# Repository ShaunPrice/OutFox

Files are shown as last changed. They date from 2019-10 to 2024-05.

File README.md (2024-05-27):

# OutFox
This is a volunteer project to help save the endangered Bell turtle species. I'm assisting the "Turtles Forever" project team in developing a fox (and dogs) detection and scaring system that uses Artificial Intelligence (AI) to identify the preditors and ward them off. The main preditor causing the damage has been foxes that are not native to Australia and are destroying the turtle nests.

This is the working prototype (PCB not validated) for the solution. It uses MobileNet AI model as it already detects many species of foxes, dogs and wolves.

*Any assistance in this project is welcome!!!*

## Articles About the Project
https://www.abc.net.au/news/2018-03-07/turtle-hatchlings-offer-hope-endangered-bells-turtle/9522182
https://northerntablelands.lls.nsw.gov.au/resource-hub/media-releases/2016/work-begins-on-bells-turtle-recovery-project

Fox and other nuisance animal detection and frightening device. Uses cameras and AI to detect and identify only the nuisance animals.
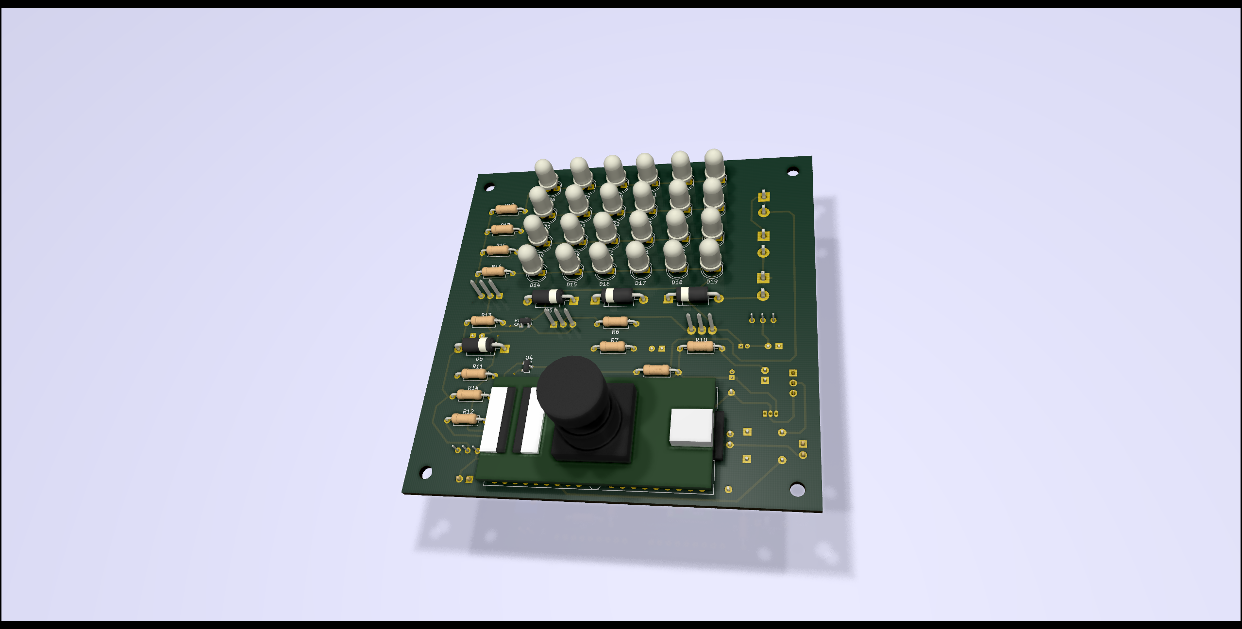
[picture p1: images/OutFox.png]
OutFox Control Board


*This is a Work in Progress*
# Notes for using the Seeed Studio MAIX Bit and the Kendryte K210

## Sipeed MAix BiT for RISC-V AI+IoT
The core of the system is the Sipeed BiT board with camera available from Seeed. 
https://www.seeedstudio.com/Sipeed-MAix-BiT-for-RISC-V-AI-IoT-p-2872.html

This board uses a Kendryte K210 Neural Accellerator for at the edge AI. The board consumes less than 1 Watt of power.

If using this board and camera for night vision using the IR LEDs you'll need to unscrew the lense from the camera and remove the small square IR filter from the back of the lense.

The documentation for this processor is available here:
https://maixpy.sipeed.com/en/

## SiSpeed Downloads
http://dl.sipeed.com/MAIX/
https://github.com/sipeed

## Uploading files and firmware
Use uPyLoader for uploading files and executing script
Use kloader_windows for uploading firmware

The details of obtaining and using these tools is available from the Sipeed website:

https://maixpy.sipeed.com/en/get_started/upload_script.html

## MaixPy Firmware
Builds:   http://dl.sipeed.com/MAIX/MaixPy/release/master/
GitHub: https://github.com/sipeed/MaixPy/releases

## Train, Convert and Run Models for MaixPy 
The following article explains how to train, convert and run AI modules on the MAix BiT and other modules using the Kendryte K210 processor.
https://bbs.sipeed.com/t/topic/682

### Package Kfpkg files
http://blog.sipeed.com/p/390.html
**Note 1:** *SD library does not support long file names.*
**Note 2:** *name.kmodel files are in the zipped file name.kfpkg*

kfpkg files are zipped files containing the following files:

	model.kmodel file that is the inference model
	flash-list.json file that tells the loaded where to put the model in flash memory
	
A typical kfpkg flash-list.json file is below where facedetect.kmodel is the name of the kmodel file:
'''json
{
    "version": "0.1.0",
     "files": [
        {
            "address": 0x00300000,
            "bin": "facedetect.kmodel",
            "sha256Prefix": false
        }
    ]
}
'''

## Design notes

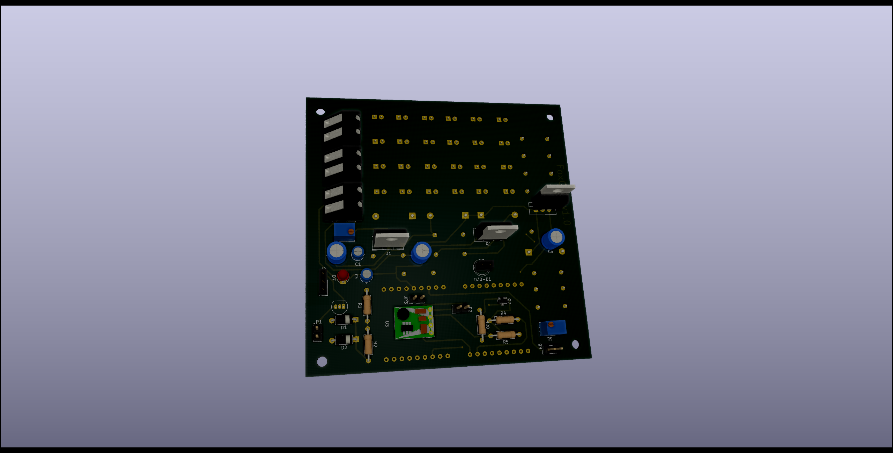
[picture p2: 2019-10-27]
OutFox_KiCAD_Electronics/FoxCam_back.png

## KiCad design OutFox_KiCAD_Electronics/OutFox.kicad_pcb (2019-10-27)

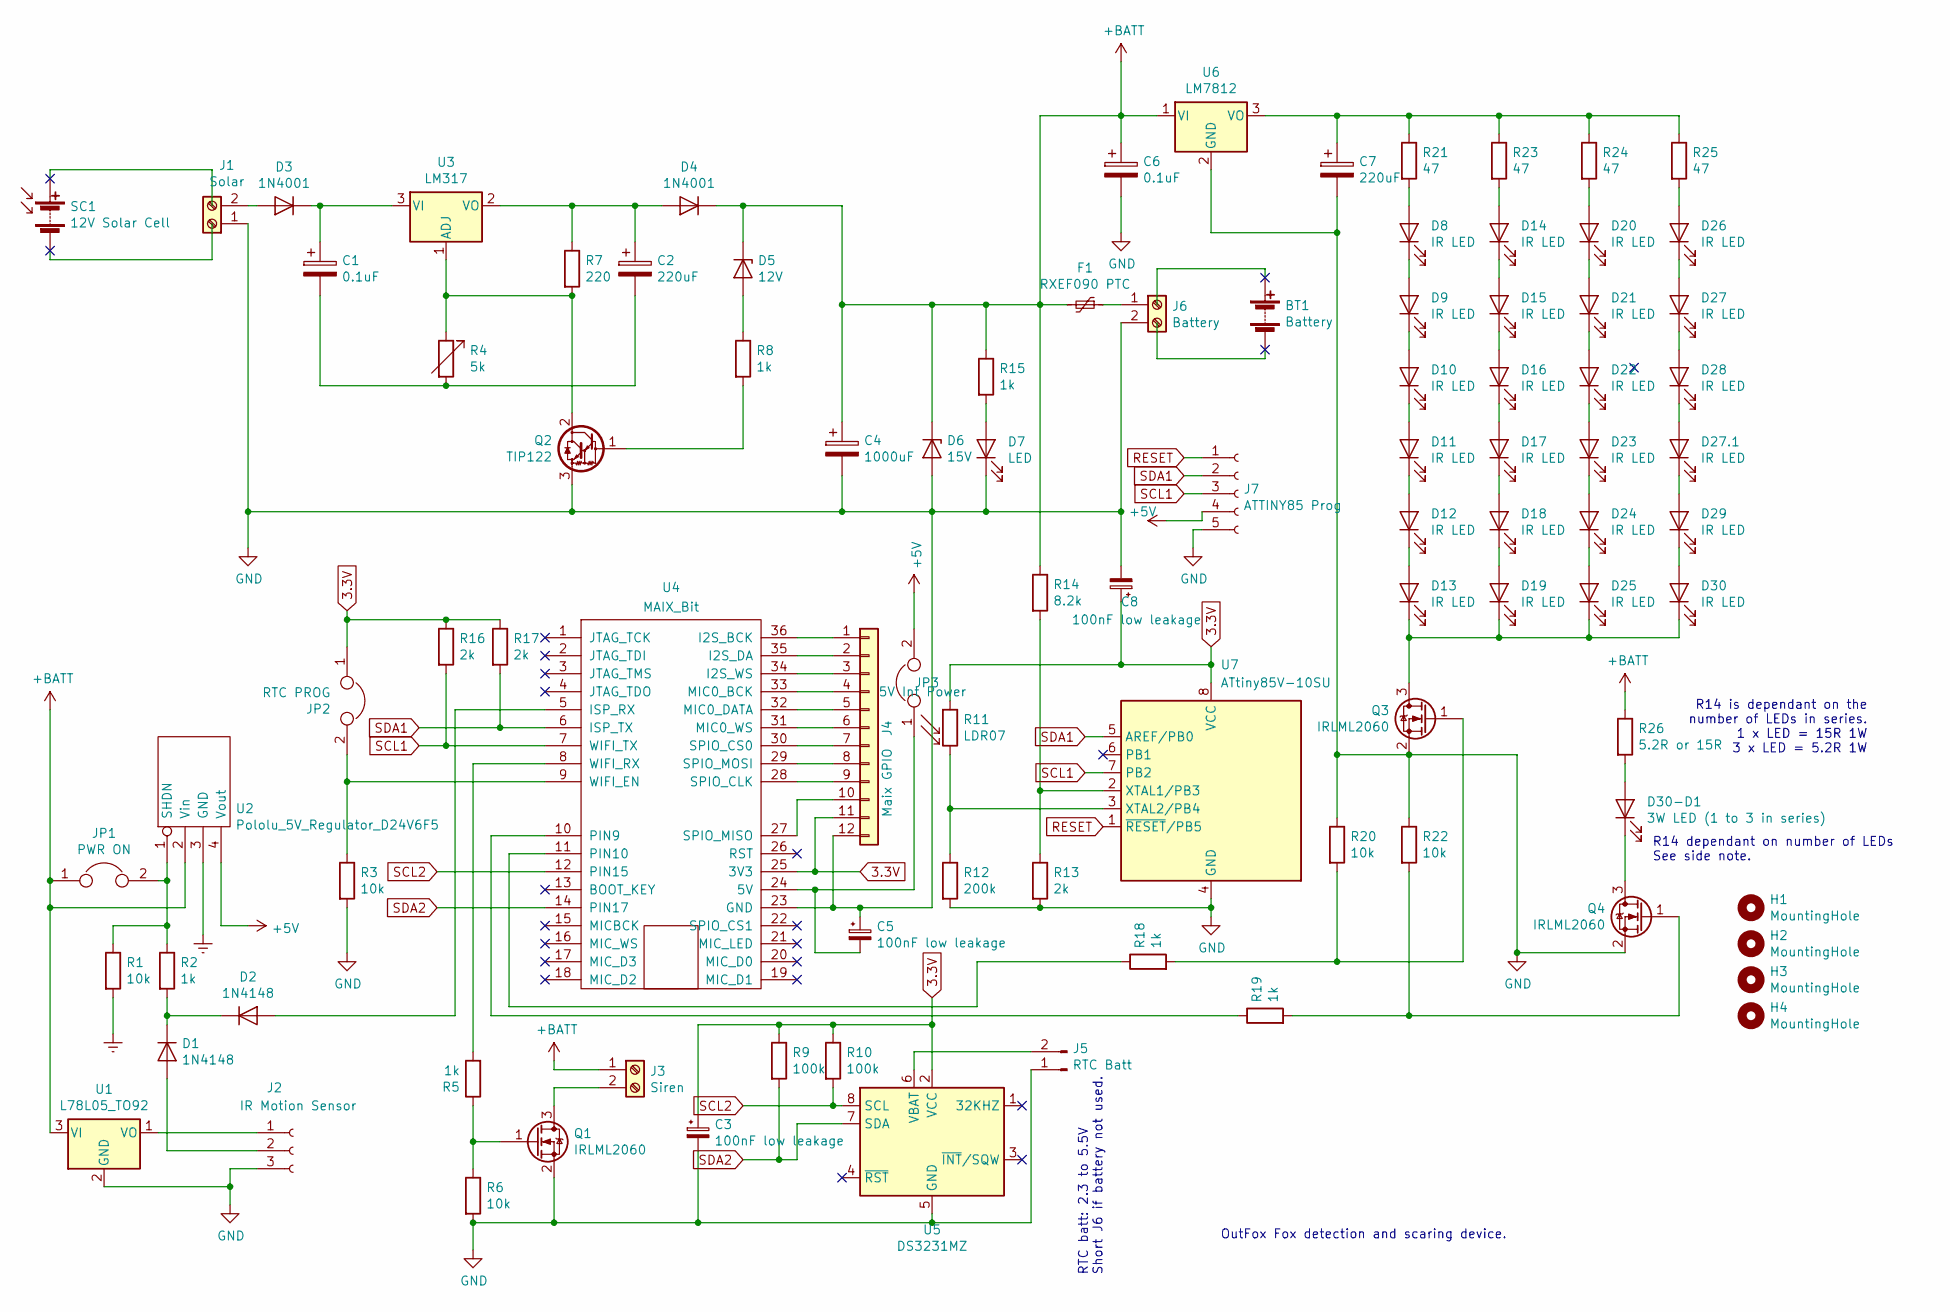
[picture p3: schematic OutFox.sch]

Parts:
BT1: Battery
C1, C6: 0.1uF; CP_Radial_D4.0mm_P1.50mm
C2, C7: 220uF; CP_Radial_D5.0mm_P2.50mm
C3, C5, C8: 100nF low leakage; C_0603_HandSoldering
C4: 1000uF; CP_Radial_D5.0mm_P2.50mm
D1, D2: 1N4148; D_A-405_P7.62mm_Horizontal
D3, D4: 1N4001; D_DO-15_P12.70mm_Horizontal
D5: 12V; D_DO-15_P12.70mm_Horizontal
D6: 15V; D_DO-15_P12.70mm_Horizontal
D7: LED; LED_D3.0mm
D8, D9, D10, D11, D12, D13, D14, D15, D16, D17, D18, D19, D20, D21, D22, D23, D24, D25, D26, D27, D27.1, D28, D29, D30: IR LED; LED_D5.0mm
D30-D1: 3W LED (1 to 3 in series); LED_D5.0mm
F1: RXEF090 PTC; Fuse_TE5_Littlefuse-395Series
H1, H2, H3, H4: MountingHole; MountingHole_3.2mm_M3
J1: Solar; TerminalBlock_bornier-2_P5.08mm
J2: IR Motion Sensor; Pin_Header_Straight_1x03_Pitch2.54mm
J3: Siren; TerminalBlock_bornier-2_P5.08mm
J4: Maix GPIO; Socket_Strip_Straight_1x12_Pitch2.54mm
J5: RTC Batt; JST_PH_B2B-PH-K_02x2.00mm_Straight
J6: Battery; TerminalBlock_bornier-2_P5.08mm
J7: ATTINY85 Prog; Pin_Header_Straight_1x05_Pitch2.54mm
JP1: PWR ON; Pin_Header_Straight_1x02_Pitch2.54mm
JP2: RTC PROG; Pin_Header_Straight_1x02_Pitch2.54mm
JP3: 5V Int Power; Pin_Header_Straight_1x02_Pitch2.54mm
Q1, Q3, Q4: IRLML2060; SOT-23
Q2: TIP122; TO-220-3_Vertical
R1, R3, R6, R20, R22: 10k; R_Axial_DIN0207_L6.3mm_D2.5mm_P10.16mm_Horizontal
R2, R5, R8, R15, R18, R19: 1k; R_Axial_DIN0207_L6.3mm_D2.5mm_P10.16mm_Horizontal
R4: 5k; Potentiometer_Trimmer_Bourns_3266Y
R7: 220; R_Axial_DIN0207_L6.3mm_D2.5mm_P10.16mm_Horizontal
R9, R10: 100k; R_0603_HandSoldering
R11: LDR07; R_Axial_DIN0204_L3.6mm_D1.6mm_P2.54mm_Vertical
R12: 200k; R_0603_HandSoldering
R13, R16, R17: 2k; R_0603_HandSoldering
R14: 8.2k; R_0603_HandSoldering
R21, R23, R24, R25: 47; R_Axial_DIN0207_L6.3mm_D2.5mm_P10.16mm_Horizontal
R26: 5.2R or 15R; R_Axial_DIN0207_L6.3mm_D2.5mm_P10.16mm_Horizontal
SC1: 12V Solar Cell
U1: L78L05_TO92; TO-92_Inline_Narrow_Oval
U2: Pololu_5V_Regulator_D24V6F5; Polulu_Voltage_Regulator
U3: LM317; TO-220
U4: MAIX_Bit; MAIXBit
U5: DS3231MZ; SOIC-8_3.9x4.9mm_Pitch1.27mm
U6: LM7812; TO-220-3_Vertical
U7: ATtiny85V-10SU; SOIC-8-N

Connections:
3.3V: C3.1, C8.1, J4.11, JP2.1, R9.1, R10.1, R11.1, R16.1, R17.1, U4.25 (3V3), U5.2 (VCC), U7.8 (VCC)
+5V: J7.4, JP3.2, U2.4 (Vout)
+BATT: C4.1, C6.1, D4.1 (K), D5.1 (K), D6.1 (K), F1.2, J3.1, JP1.1, R14.1, R15.1, R26.1, U1.3 (VI), U2.2 (Vin), U6.1 (VI)
Earth: R1.2, U2.3 (GND)
GND: C3.2, C4.2, C5.1, C6.2, C7.2, C8.2, D6.2 (A), D7.1 (K), J1.1, J2.3 (GND), J4.12, J5.1, J6.2, J7.5, Q1.2 (S), Q2.3 (E), Q3.2 (S), Q4.2 (S), R3.2, R6.2, R12.2, R13.2, R20.1, R22.1, U1.2 (GND), U4.23 (GND), U5.5 (GND), U6.2 (GND), U7.4 (GND)
unnamed: C1.1, D3.1 (K), U3.3 (VI)
unnamed: C1.2, C2.2, R4.2
unnamed: C2.1, D4.2 (A), R7.1, U3.2 (VO)
unnamed: C5.2, JP3.1, U4.24 (5V)
unnamed: C7.1, R21.1, R23.1, R24.1, R25.1, U6.3 (VO)
unnamed: D1.1 (K), D2.1 (K), R2.2
unnamed: D1.2 (A), J2.2 (OUT)
unnamed: D2.2 (A), U4.5 (ISP_RX)
unnamed: D3.2 (A), J1.2
unnamed: D5.2 (A), R8.1
unnamed: D7.2 (A), R15.2
unnamed: D8.1 (K), D9.2 (A)
unnamed: D8.2 (A), R21.2
unnamed: D10.1 (K), D11.2 (A)
unnamed: D9.1 (K), D10.2 (A)
unnamed: D11.1 (K), D12.2 (A)
unnamed: D12.1 (K), D13.2 (A)
unnamed: D13.1 (K), D19.1 (K), D25.1 (K), D30.1 (K), Q3.3 (D)
unnamed: D14.1 (K), D15.2 (A)
unnamed: D14.2 (A), R23.2
unnamed: D15.1 (K), D16.2 (A)
unnamed: D16.1 (K), D17.2 (A)
unnamed: D17.1 (K), D18.2 (A)
unnamed: D18.1 (K), D19.2 (A)
unnamed: D20.1 (K), D21.2 (A)
unnamed: D20.2 (A), R24.2
unnamed: D21.1 (K), D22.2 (A)
unnamed: D22.1 (K), D23.2 (A)
unnamed: D23.1 (K), D24.2 (A)
unnamed: D24.1 (K), D25.2 (A)
unnamed: D26.1 (K), D27.2 (A)
unnamed: D26.2 (A), R25.2
unnamed: D27.1 (K), D28.2 (A)
unnamed: D27.1.1 (K), D29.2 (A)
unnamed: D27.1.2 (A), D28.1 (K)
unnamed: D29.1 (K), D30.2 (A)
unnamed: D30-D1.1 (K), Q4.3 (D)
unnamed: D30-D1.2 (A), R26.2
unnamed: F1.1, J6.1
unnamed: J2.1 (5V), U1.1 (VO)
unnamed: J3.2, Q1.3 (D)
unnamed: J4.1, U4.36 (I2S_BCK)
unnamed: J4.2, U4.35 (I2S_DA)
unnamed: J4.3, U4.34 (I2S_WS)
unnamed: J4.4, U4.33 (MIC0_BCK)
unnamed: J4.5, U4.32 (MIC0_DATA)
unnamed: J4.6, U4.31 (MIC0_WS)
unnamed: J4.7, U4.30 (SPIO_CS0)
unnamed: J4.8, U4.29 (SPIO_MOSI)
unnamed: J4.9, U4.28 (SPIO_CLK)
unnamed: J4.10, U4.27 (SPIO_MISO)
unnamed: J5.2, U5.6 (VBAT)
unnamed: JP1.2, R1.1, R2.1, U2.1 (SHDN)
unnamed: JP2.2, R3.1, U4.9 (WIFI_EN)
unnamed: Q1.1 (G), R5.1, R6.1
unnamed: Q2.1 (B), R8.2
unnamed: Q2.2 (C), R4.1, R7.2, U3.1 (ADJ)
unnamed: Q3.1 (G), R18.2, R20.2
unnamed: Q4.1 (G), R19.2, R22.2
unnamed: R5.2, U4.8 (WIFI_RX)
unnamed: R11.2, R12.1, U7.3 (XTAL2/PB4)
unnamed: R13.1, R14.2, U7.2 (XTAL1/PB3)
unnamed: R18.1, U4.11 (PIN10)
unnamed: R19.1, U4.10 (PIN9)
RESET: J7.1, U7.1 (~RESET~/PB5)
SCL1: J7.3, R16.2, U4.7 (WIFI_TX), U7.7 (PB2)
SCL2: R10.2, U4.12 (PIN15), U5.8 (SCL)
SDA1: J7.2, R17.2, U4.6 (ISP_TX), U7.5 (AREF/PB0)
SDA2: R9.2, U4.14 (PIN17), U5.7 (SDA)

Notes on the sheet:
R14 is dependant on the number of LEDs in series. 1 x LED = 15R 1W 3 x LED = 5.2R 1W
R14 dependant on number of LEDs See side note.
RTC batt: 2.3 to 5.5V Short J6 if battery not used.
OutFox Fox detection and scaring device.

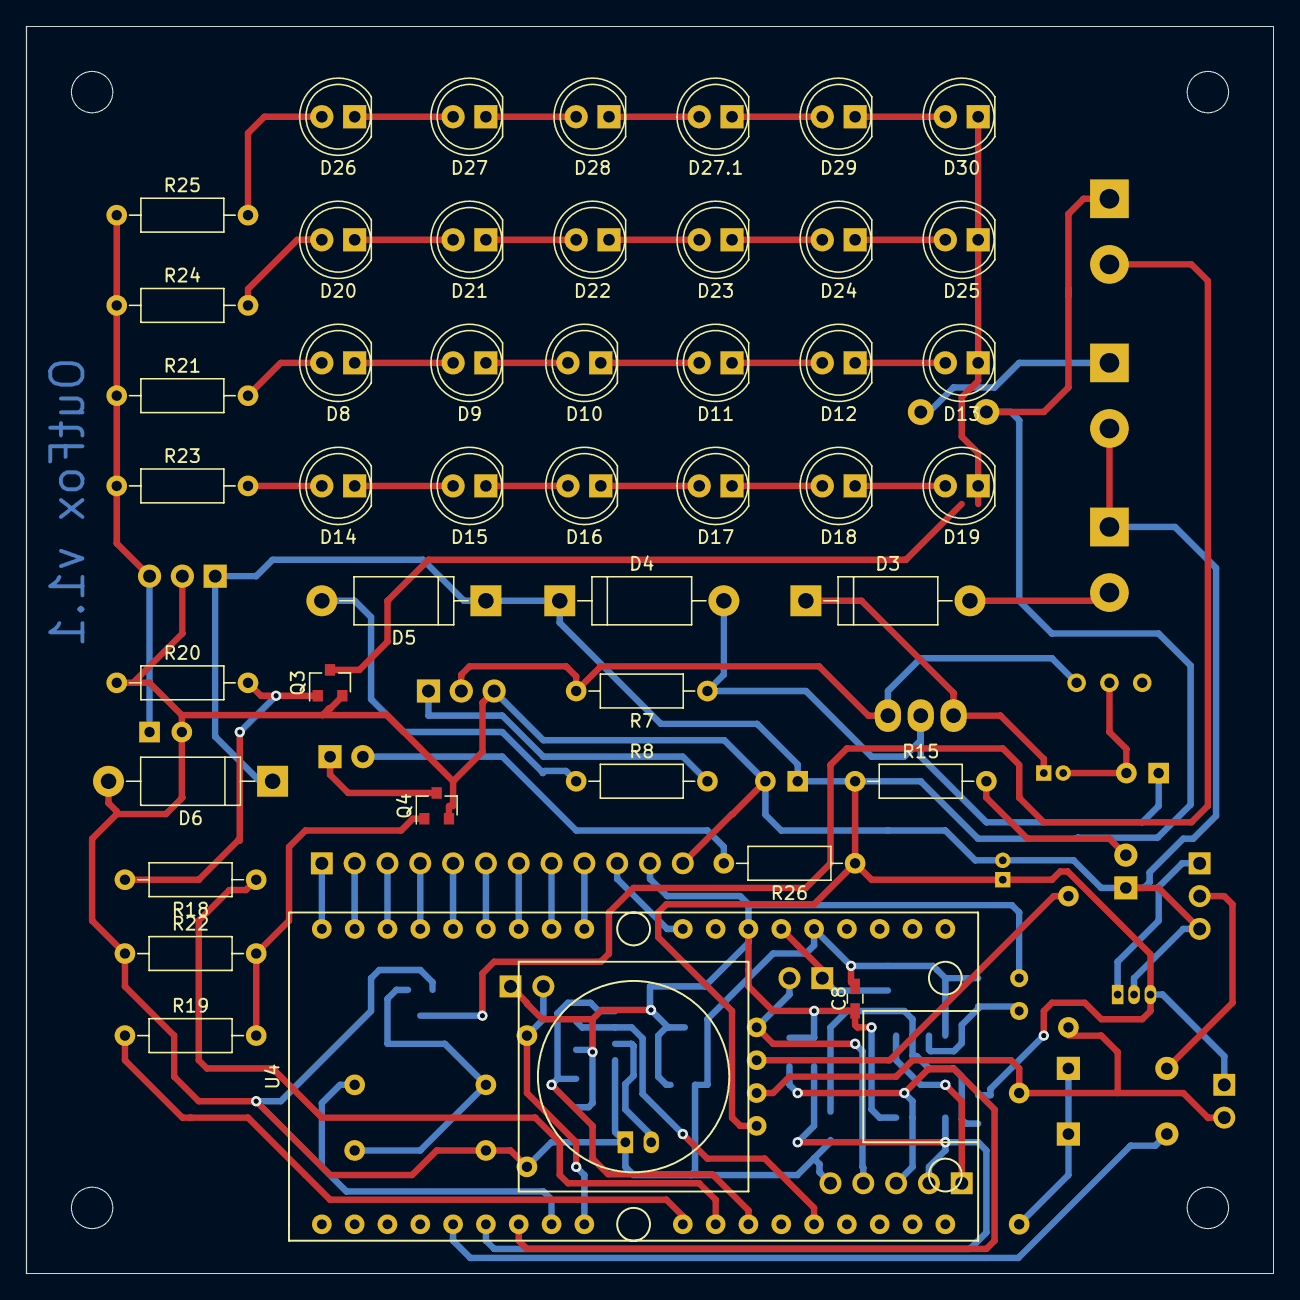
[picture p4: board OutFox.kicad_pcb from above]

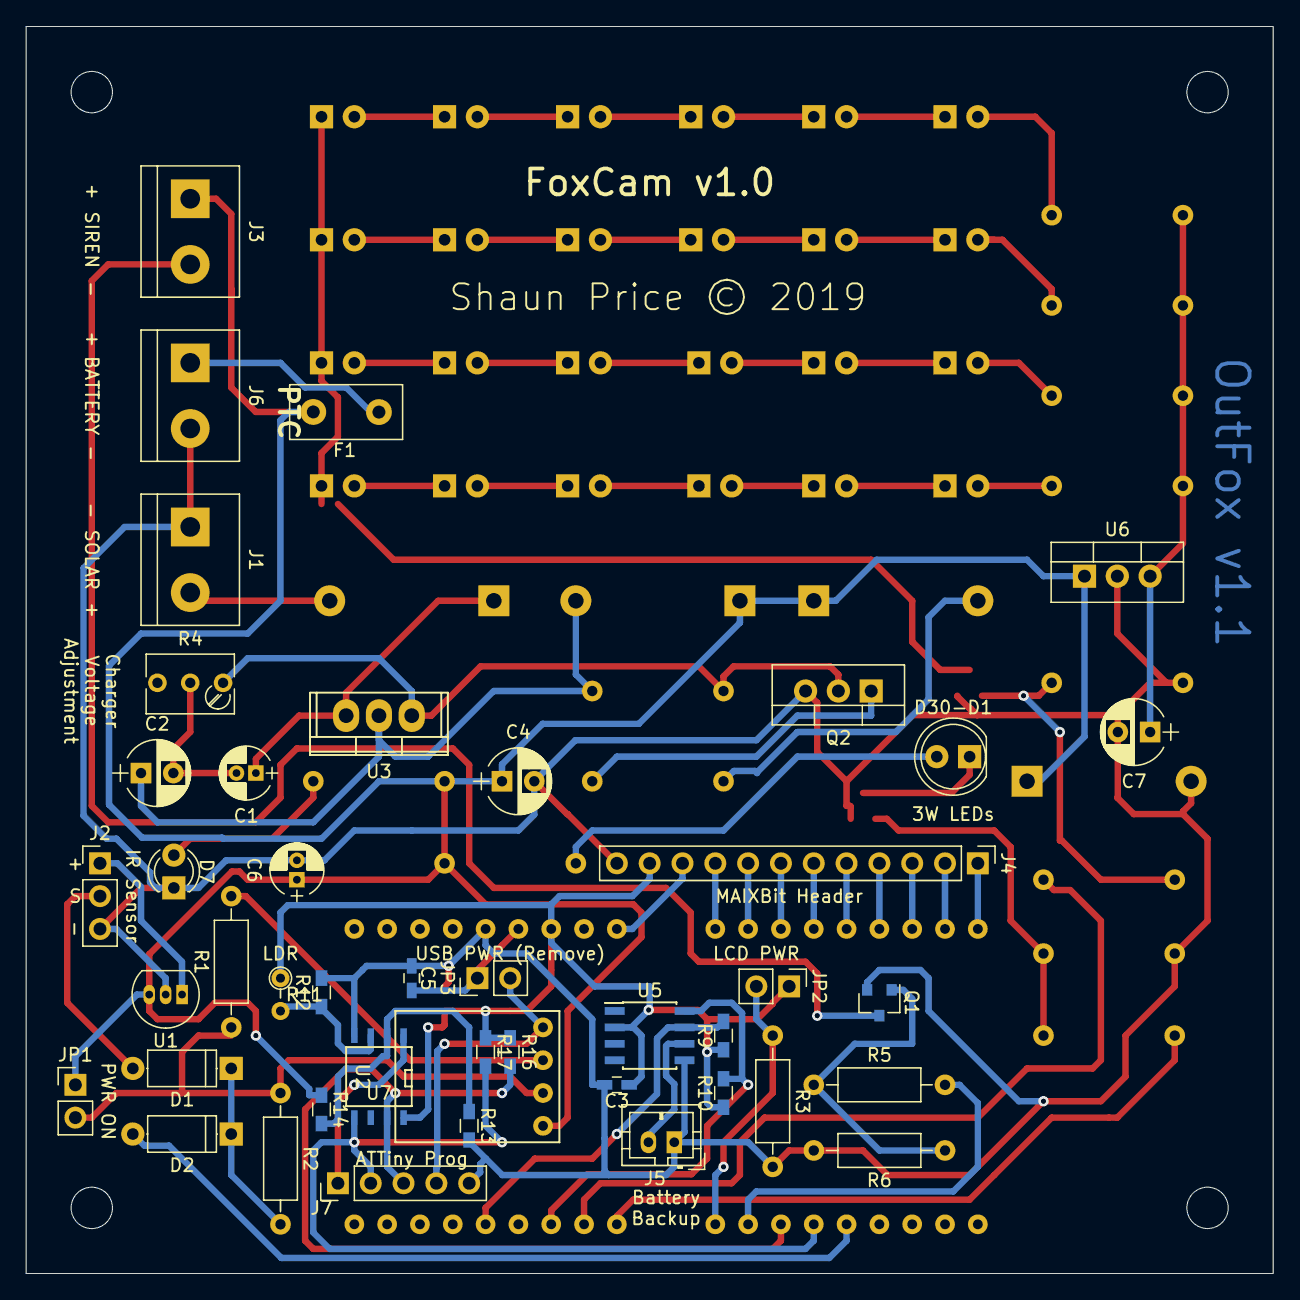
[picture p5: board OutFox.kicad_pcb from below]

Board: 2 copper layers, 96.5 x 96.5 mm, 92 parts (44 on the bottom side), 74 nets.

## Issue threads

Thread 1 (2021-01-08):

Hardware setup

rmuellerjr, 2021-01-08:
Great project! I'm looking for info about the rest of your hardware setup in addition to the MAix board, such as; power management HAT, power source, cell modem or usb storage, etc.

Thanks!

ShaunPrice, 2021-08-25:
Sorry for the delay. I've been very busy. Most of the project works but there was an issue with the regulator not doing what the specs said it should. I'll likely be doing more work on this over the next few months.

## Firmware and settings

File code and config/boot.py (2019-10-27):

import sensor, image, lcd, time, utime, uos,sys, math, ujson
import KPU as kpu
from Maix import GPIO, FPIOA
from board import board_info
from fpioa_manager import fm
from machine import UART, I2C

version = "1.0.0"
animals = ['red fox','kit fox','dingo','dog', 'wolf','grey fox','coyote']
timeout_duration = 30 # How long the camera is on for in seconds
timeout_extended_duration = 30 # How long to keep the camera on after a detection

# I2C Addresses
RTC_I2C_ADDR  = 0x68
SECONDS_ADDR  = 0x00
MINUTES_ADDR  = 0x01
HOURS_ADDR    = 0x02
WEEKDAY_ADDR  = 0x03
MONTHDAY_ADDR = 0x04
MONTH_ADDR    = 0x05
YEAR_ADDR     = 0x06
TEMP_MSB_ADDR = 0x11
TEMP_LSB_ADDR = 0x12

# Calendar variables
year = 19
month = 1
day = 1
hour = 0
minute = 0
second = 0
daylight = True
temperature = 0

# Sunrise and sunset times for each month
# Assumes Lat/Lon of -31:30:00/152:30:00
# Times were calculated using:
# https://www.esrl.noaa.gov/gmd/grad/solcalc/sunrise.html
# Sunrise and sunset are in hours.
# Fractional part are in hours (e.g. 0.5 = 30 mins)
# Format (sunrise,sunset)
DAYLIGHT_TIMES = ((5.4,19.2), \
             (5.8,19.0), \
             (6.2,18.5), \
             (6.5,17.8), \
             (6.8,17.4), \
             (7.1,17.3), \
             (7.1,17.4), \
             (6.8,17.7), \
             (6.2,18.1), \
             (5.3,18.3), \
             (5.1,18.7), \
             (5.0,19.1))

# Set defaults
DAYLIGHT_START = 7
DAYLIGHT_END = 5

# Pins
'''
Function    Physical    Label       PIN     GPIO
====================================================
PWR_OFF      5          ISP_RX      PIN6    GPIO6
UC_SDA       6          ISP_TX      PIN7    GPIOHS9
UC_SCL       7          WIFI_TX     PIN8    GPIOHS10
SIREN        8          WIFI_RX     PIN7    GPIO7
RTC_PROG     9          WIFI_EN     PIN8    GPIOHS0
LED_3W      10          PIN9        PIN9    GPIOHS1
IR_LEDS     11          PIN10       PIN10   GPIOHS2
RTC SCL     17          SPI0_CLK    PIN14   GPIOHS8
RTC SDA     18          MICBCK      PIN15   GPIOHS7

###################################################
For the daughter board version:
========================
PWR_OFF      7          WIFI_TX     PIN6    GPIO6
SIREN        8          WIFI_RX     PIN7    GPIO7
RTC_PROG     9          WIFI_EN     PIN8    GPIOHS0
LED_3W      10          PIN9        PIN9    GPIOHS1
IR_LEDS     11          PIN10       PIN10   GPIOHS2
RTC SDA     33          MIC0_BCK    PIN32   GPIOHS7
RTC SCL     34          I2S_WS      PIN33   GPIOHS8
UC_SDA      35          I2S_DA      PIN34   GPIOHS9
UC_SCL      36          I2S_BCK     PIN35   GPIOHS10
###################################################
'''

# GPIO Pin Mapping
PWR_OFF  = board_info.WIFI_TX
SIREN    = board_info.WIFI_RX
RTC_PROG = board_info.WIFI_EN
LED_3W   = board_info.PIN9
IR_LEDS  = board_info.PIN10
RTC_SDA  = board_info.MIC0_BCK
RTC_SCL  = board_info.I2S_WS

# Turns the RGB LED on and Red
def redLED ():
    led_r.value(0)
    led_g.value(1)
    led_b.value(1)

# Turns the RGB LED on and gREEN
def greenLED ():
    led_r.value(1)
    led_g.value(0)
    led_b.value(1)

# Turns the RGB LED on and bLUE
def blueLED ():
    led_r.value(1)
    led_g.value(1)
    led_b.value(0)

# Displays text on the LCD and the serial console
def lcd_display_text(x,y,text):
    print(text)
    if lcd_display == 1:
        lcd_display_blank(x,y)
        lcd.draw_string(x,y,text)

# Blanks out previous text on the LCD
def lcd_display_blank(x,y):
    if lcd_display == 1:
        lcd.draw_string(x,y,"                         ")

# Display image on the LCD
def lcd_display_image(img):
    if lcd_display == 1:
        lcd.display(img, oft=(50,0))

# Converts BCD to Decimal number coding
def bcd_2_dec(bcd):
    return (((bcd & 0xF0) >> 4) * 10) + (bcd & 0x0F)

# Converts Decimal to BCD Coding
def dec_2_bcd(dec):
    decade = int(dec / 10)
    LSB = dec - (decade * 10)
    MSB =  decade << 4
    BYTE = MSB + LSB
    return MSB + LSB 

# Read from I2C address of teh RTC 
def readData(address):
    data = rtc_i2c.readfrom_mem(RTC_I2C_ADDR,address,1)
    return data[0]

# Write to I2C address of the RTC
def writeData(address, data):
    rtc_i2c.writeto_mem(RTC_I2C_ADDR,address,data)

# Get the year from the RTC
def getYear():
    data = readData(YEAR_ADDR)
    return bcd_2_dec(data)

# Get the month from the RTC
def getMonth():
    data = readData(MONTH_ADDR)  & 0b0111111
    return bcd_2_dec(data)

# Get the month day from the RTC
def getDay():
    data = readData(MONTHDAY_ADDR)
    return bcd_2_dec(data)

# Get the hour from the RTC
def getHour():
    data = readData(HOURS_ADDR)
    return bcd_2_dec(data)

# Get the miunute from the RTC
def getMinute():
    data = readData(MINUTES_ADDR)
    return bcd_2_dec(data)

# Get the seconds from the RTC
def getSeconds():
    data = readData(SECONDS_ADDR)
    return bcd_2_dec(data)

# Set the year of the RTC
def setYear(_year):
    data = dec_2_bcd(_year)
    writeData(YEAR_ADDR, data)

# Set the month of the RTC
def setMonth(_month):
    data = dec_2_bcd(_month) + 0b1000000
    writeData(MONTH_ADDR, data)

# Set the month day of the RTC
def setDay(_day):
    data = data = dec_2_bcd(_day)
    writeData(MONTHDAY_ADDR, data)

# Set the hour of the RTC
def setHour(_hour):
    data = data = dec_2_bcd(_hour)
    writeData(HOURS_ADDR, data)

# Set the minute of the RTC
def setMinute(_minute):
    data = data = dec_2_bcd(_minute)
    writeData(MINUTES_ADDR, data)

# Set the seconds of the RTC
def setSeconds(_second):
    data = data = dec_2_bcd(_second)
    writeData(SECONDS_ADDR, data)

# Get the temperature from the RTC
def getTemperature():
    tempMSB = readData(TEMP_MSB_ADDR)
    tempLSB = (readData(TEMP_LSB_ADDR) >> 6) * 0.25
    tempFloat = float(tempMSB & 0b01111111) + tempLSB
    if (tempMSB & 0b10000000) > 0: # If nexagive temp
        return (float(tempMSB & 0b01111111) + tempLSB) * -1
    else:
        return tempFloat

# Get all the date and timne data from the RTC
# Returns a formated date/time string
def getDateTime():
    year =  getYear()
    month = getMonth()
    day =   getDay()
    hour =  getHour()
    minute = getMinute()
    second = getSeconds()

    return "20{:0>2d}".format(year)+"-" \
           +"{:0>2d}".format(month)+"-" \
           +"{:0>2d}".format(day)+" " \
           +"{:0>2d}".format(hour)+":" \
           +"{:0>2d}".format(minute)+":" \
           +"{:0>2d}".format(second)

# Checks if the sun is up.
# Currently set for mid to north coast of NSW Australia
# Future versions will calculate the times based on the geoloacation 
# The board also has an LDR that can be used for this purpose
def checkDaylight():
    print(getDateTime())
    hours_as_fraction = hour + (minute / 60) 

    if hours_as_fraction > DAYLIGHT_START and hours_as_fraction < DAYLIGHT_END:
        daylight = True
    else:
        daylight = False

# Used to display messages and convert terminal input to integers
def rtcInput(text):
    print(text)
    return int(input())
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

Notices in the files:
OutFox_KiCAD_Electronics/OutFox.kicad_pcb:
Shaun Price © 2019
